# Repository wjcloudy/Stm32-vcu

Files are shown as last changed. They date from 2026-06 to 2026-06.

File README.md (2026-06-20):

# stm32-vcu (ZombieVerter VCU)

Build status

Project based on the OpenInverter System by Johannes Huebner to provide a universal VCU (Vehicle Control Unit) for electric vehicle conversion projects. 

Please visit the development thread on the Openinverter Forum for more information : https://openinverter.org/forum/viewtopic.php?f=3&t=1277
Zom_V1_3

V1.3 Hardware now released. PDFs and Gerber here on Github, full Kicad 9 design is on Patreon at the 10Eur level.

## Videos on progress

Project introduction : https://vimeo.com/506480876

V1.11a On dyno with GS450h / BMW E39 : https://vimeo.com/802405172

V2.00a now available : https://vimeo.com/824494783?share=copy

V2.15a now available : https://www.youtube.com/watch?v=iwB3wxCEFo0

V2.20A now available : https://www.youtube.com/watch?v=wjlucUWX_lc

V2.40A now available : https://vimeo.com/1201141543?fl=ip&fe=ec

# Supported components

- Nissan Leaf Gen1/2/3 inverter via CAN
- Nissan Leaf Gen1/2/3 PDM (Charger and DCDC)
- Nissan LEAF Battery (all variants)
- Mitsubishi Outlander Support
- Mitsubishi Outlander drivetrain (front and rear motors/inverters) Support
- Modular BMS / SimpBMS Support
- OpenInverter CAN Support
- CCS DC fast charge via BMW i3 LIM
- CCS DC fast charging via FOCCCI https://github.com/uhi22/ccs32clara
- Chademo DC fast charge
- ISA Shunt / BMW SBOX / VW EBOX supported via CAN
- Lexus GS450H inverter / gearbox via sync serial
- Lexus GS300H inverter / gearbox via sync serial
- Toyota Prius/Yaris/Auris Gen 3 inverters via sync serial
- BMW E46 CAN support
- BMW E39 CAN support
- BMW E65 CAN Support
- BMW E31 CAN Support
- Mid 2000s VAG Can support
- Subaru vehicle support
- Opel Ampera / Chevy Volt 6.5kw cabin heater
- VW LIN based 6.5kw cabin heater
- Elcon charger Support
- OBD2 Can support
- TESLA Gen 2 DCDC Converter Can support

# Contributing

Information on how to contribute to this open source project can be found [Contributing Guide](./CONTRIBUTING.md)

# Compiling
You will need the arm-none-eabi toolchain: https://developer.arm.com/open-source/gnu-toolchain/gnu-rm/downloads
On Linux this can be installed by typing:

`sudo apt install gcc-arm-none-eabi`

The only external depedencies are libopencm3 and libopeninv. You can download and build this dependency by typing

`make get-deps`

Now you can compile stm32-vcu by typing

`make`

# Tests

Build the tests

`make Tests`

Run the tests

`./test/test_vcu`

And upload it to your board using a JTAG/SWD adapter, the updater.py script or the esp8266 web interface

I use CodeBlocks IDE :  https://www.codeblocks.org/

Sept 21 : V1 hardware and firmware from "Master" branch now running in my E46 Touring and E39 vehicles.

March 24 : V1.1 Hardware and V2.05A firmware now running in 3 vehicles :

-BMW E39 with Lexus GS450H Drivetrain, Tesla PCS, ISA Shunt , Chademo Fast Charge

-BMW E46 Touring with Nissan Leaf Gen 1 Drivetrain, Outlander Charger / DCDC, ISA Shunt , CCS Fast Charge

-BMW E31 with Tesla LDU Drivetrain, Tesla DCDC, ISA Shunt , Chademo Fast Charge

All hardware / software is tested in these vehicles before release. More vehicles with different configuration in progress to ensure as much testing as possible.

Apr 26 : Added Zombie Relay box V1 full kicad project to hardware directory.

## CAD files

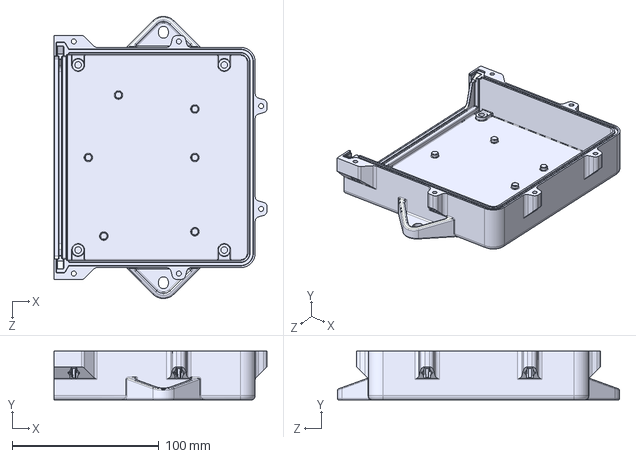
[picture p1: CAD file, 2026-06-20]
3d_Printable_Case/zombiecase_V3.1_2mounts_169mm.STEP
145.0 x 33.4 x 192.0 mm

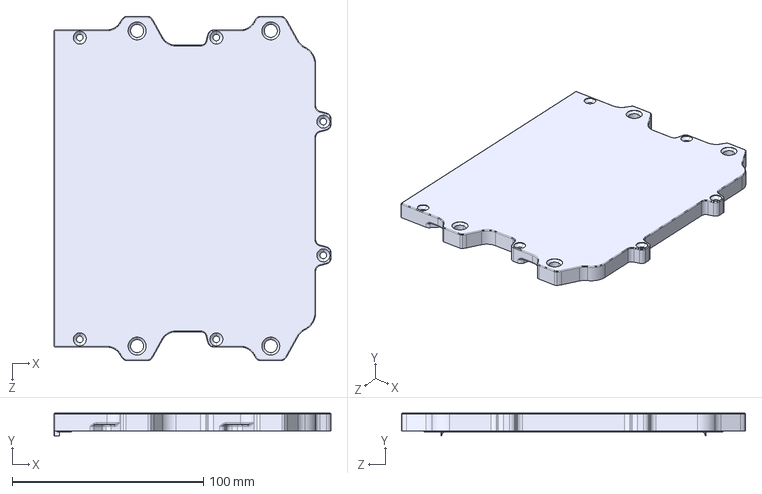
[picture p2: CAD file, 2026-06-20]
3d_Printable_Case/Zombiecase_StackingTopV3.2.STEP
145.0 x 12.0 x 180.1 mm

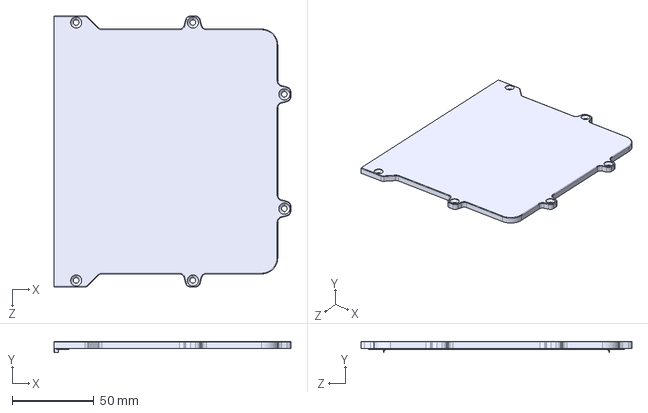
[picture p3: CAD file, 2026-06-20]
3d_Printable_Case/Zombiecase_topV3.1.STEP
145.0 x 6.95 x 166.0 mm

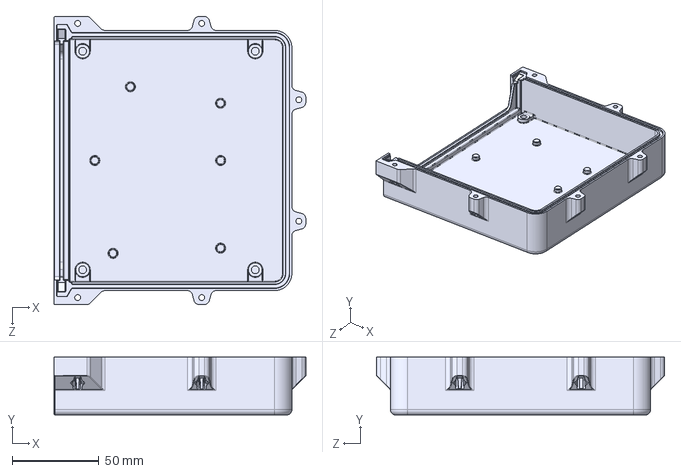
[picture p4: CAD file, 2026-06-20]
3d_Printable_Case/zombiecase_V3.1.STEP
145.0 x 33.4 x 166.0 mm

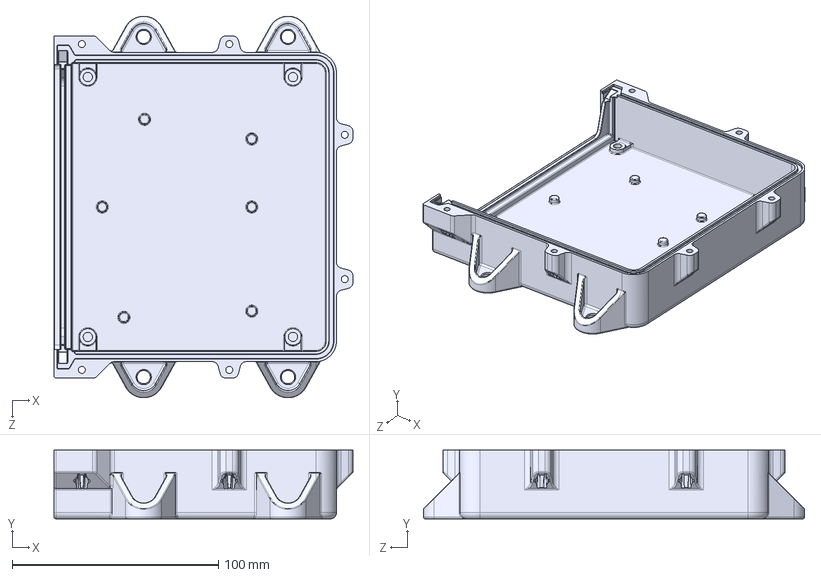
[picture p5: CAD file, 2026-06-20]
3d_Printable_Case/zombiecase_V3.1wMountingTabs.STEP
145.0 x 33.4 x 185.0 mm

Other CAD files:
3d_Printable_Case/Zombiecase_StackingTopV3.2.3MF
3d_Printable_Case/zombiecase_V3.1_2mounts_169mm.3MF

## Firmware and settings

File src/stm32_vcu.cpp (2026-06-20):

/*
 * This file is part of the ZombieVerter project.
 *
 * Copyright (C) 2024 Tom de Bree <tom@voltinflux.com>
 * Copyright (C) 2010 Johannes Huebner <contact@johanneshuebner.com>
 * Copyright (C) 2010 Edward Cheeseman <cheesemanedward@gmail.com>
 * Copyright (C) 2009 Uwe Hermann <uwe@hermann-uwe.de>
 * Copyright (C) 2019-2022 Damien Maguire <info@evbmw.com>
 *
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
 * You should have received a copy of the GNU General Public License
 * along with this program.  If not, see <http://www.gnu.org/licenses/>.
 */

#include "BMW_E31.h"
#include "BMW_E39.h"
#include "BMW_E65.h"
/*
 * BMW PHEV SME integration (BmwPhevBMS):
 *   BMS_Mode=6  →  cell Vmin/Vmax, Tmin/Tmax, SOC, isolation, power limits
 *   ShuntType=5  →  pack voltage/current, precharge setpoint, contactor control
 * Both params must point to the same CAN bus (BMSCan = ShuntCan).
 * See include/bmw_phev_bms.h for the full protocol documentation.
 */
#include "CANSPI.h"
#include "CPC.h"
#include "Can_OBD2.h"
#include "Can_OI.h"
#include "Can_VAG.h"
#include "E65_Lever.h"
#include "ElconCharger.h"
#include "ElconDCDC.h"
#include "F30_Lever.h"
#include "Foccci.h"
#include "GS450H.h"
#include "JLR_G1.h"
#include "JLR_G2.h"
#include "MGCoolantHeater.h"
#include "NissanPDM.h"
#include "NoInverter.h"
#include "NoVehicle.h"
#include "OutlanderCanHeater.h"
#include "OutlanderHeartBeat.h"
#include "TeslaDCDC.h"
#include "VWAirHeater.h"
#include "VWCoolantHeater.h"
#include "V_Classic.h"
#include "amperacharger.h"
#include "amperaheater.h"
#include "anain.h"
#include "bms.h"
#include "bmw_phev_bms.h" // BMW PHEV Gen3/4 SME — BMS + contactor control
#include "bmw_sbox.h"
#include "canmap.h"
#include "cansdo.h"
#include "chademo.h"
#include "chargerhw.h"
#include "chargerint.h"
#include "daisychainbms.h"
#include "dcdc.h"
#include "digio.h"
#include "digipot.h"
#include "errormessage.h"
#include "extCharger.h"
#include "heater.h"
#include "hwdefs.h"
#include "hwinit.h"
#include "i3LIM.h"
#include "inverter.h"
#include "iomatrix.h"
#include "isa_shunt.h"
#include "kangoobms.h"
#include "leafbms.h"
#include "leafinv.h"
#include "linbus.h"
#include "my_math.h"
#include "my_string.h"
#include "noHeater.h"
#include "no_Lever.h"
#include "nocharger.h"
#include "notused.h"
#include "outlanderCharger.h"
#include "outlanderinverter.h"
#include "param_save.h"
#include "params.h"
#include "preheater.h"
#include "printf.h"
#include "rearoutlanderinverter.h"
#include "sdocommands.h"
#include "shifter.h"
#include "simpbms.h"
#include "stm32_can.h"
#include "stm32scheduler.h"
#include "subaruvehicle.h"
#include "temp_meas.h"
#include "terminal.h"
#include "terminalcommands.h"
#include "teslaCharger.h"
#include "throttle.h"
#include "utils.h"
#include "vag_sbox.h"
#include "vehicle.h"
#include <libopencm3/stm32/can.h>
#include <libopencm3/stm32/exti.h>
#include <libopencm3/stm32/iwdg.h>
#include <libopencm3/stm32/rtc.h>
#include <libopencm3/stm32/spi.h>
#include <libopencm3/stm32/timer.h>
#include <libopencm3/stm32/usart.h>
#include <stdint.h>

#define PRECHARGE_TIMEOUT 5 // 5s

#define PRINT_JSON 0

extern "C" void __cxa_pure_virtual() {
  while (1)
    ;
}

static Stm32Scheduler *scheduler;
static bool chargeMode = false;
static bool chargeModeDC = false;
static bool ChgLck = false;
static CanHardware *canInterface[3];
static CanMap *canMap;
static CanSdo *canSdo;
static ChargeModes targetCharger;
static ChargeInterfaces targetChgint;
static uint8_t ChgSet; // Temp variable storing Param::Chgctrl. 0=enable,
                       // 1=disable, 2=timer.
static bool RunChg;
static uint8_t ChgHrs_tmp;
static uint8_t ChgMins_tmp;
static uint16_t ChgDur_tmp;
static uint32_t ChgTicks = 0, ChgTicks_1Min = 0;
static bool StartSig = false;
static bool ACrequest = false;
static bool initbyStart = false;
static bool initbyCharge = false;
static bool OutlanderCAN = false;
static bool ExtHVreq = false;
static bool CheckHVIL = 0;
static bool HVILok = 0;

static volatile unsigned days = 0, hours = 0, minutes = 0, seconds = 0,
                         alarm = 0; // != 0 when alarm is pending

static uint16_t rlyDly = 25;
static uint16_t prechargeMinTime = 100;

// Instantiate Classes
static BMW_E31 e31Vehicle;
static BMW_E65 e65Vehicle;
static BMW_E39 e39Vehicle;
static Can_VAG vagVehicle;
static SubaruVehicle subaruVehicle;
static GS450HClass gs450Inverter;
static LeafINV leafInv;
static NissanPDM chargerPDM;
static teslaCharger ChargerTesla;
static ElconCharger ChargerElcon;
static notused UnUsed;
static noCharger nochg;
static extCharger chgdigi;
static amperaCharger ampChg;
static outlanderCharger outChg;
static FCChademo chademoFC;
static i3LIMClass LIMFC;
static CPCClass CPCcan;
static FoccciClass Focccican;
static Can_OI openInv;
static NoInverterClass NoInverter;
static OutlanderInverter outlanderInv;
static noHeater Heaternone;
static AmperaHeater amperaHeater;
static OutlanderCanHeater outlanderCanHeater;
static no_Lever NoGearLever;
static F30_Lever F30GearLever;
static E65_Lever E65GearLever;
static JLR_G1 JLRG1shift;
static JLR_G2 JLRG2shift;
static vwCoolantHeater heaterCoolantVW;
static mgCoolantHeater heaterCoolantMG;
static vwAirHeater heaterAirVW;
static NoVehicle VehicleNone;
static V_Classic classVehicle;
static Inverter *selectedInverter = &openInv;
static Vehicle *selectedVehicle = &VehicleNone;
static Heater *selectedHeater = &Heaternone;
static Chargerhw *selectedCharger = &chargerPDM;
static Chargerint *selectedChargeInt = &UnUsed;
static Shifter *selectedShifter = &NoGearLever;
static BMS BMSnone;
static SimpBMS BMSsimp;
static LeafBMS BMSleaf;
static DaisychainBMS BMSdaisychain;
static KangooBMS BMSRenaultKangoo33;
static BmwPhevBMS
    BMSbmwphev; // BMW PHEV SME — used when BMS_Mode=6 and ShuntType=5
static DCDC DCDCnone;
static TeslaDCDC DCDCTesla;
static ElconDCDC ElconDC;
static BMS *selectedBMS = &BMSnone;
static DCDC *selectedDCDC = &DCDCnone;
static Can_OBD2 canOBD2;
static Shifter shifterNone;
static RearOutlanderInverter rearoutlanderInv;
static LinBus *lin;
static Preheater preheater;

///////////////////////////////////////////////////////////////////////////////////////////////////////////////////////////////
static void Ms200Task(void) {
  int opmode = Param::GetInt(Param::opmode);

  selectedVehicle->Task200Ms();
  if (opmode == MOD_CHARGE)
    selectedCharger->Task200Ms();

  // in chademo , we do not want to run the 200ms task unless in dc charge mode
  if (targetChgint == ChargeInterfaces::Chademo && chargeModeDC)
    selectedChargeInt->Task200Ms();
  // In case of the LIM we want to send it all the time if lim in use
  if ((targetChgint == ChargeInterfaces::i3LIM) ||
      (targetChgint == ChargeInterfaces::Unused) ||
      (targetChgint == ChargeInterfaces::CPC) ||
      (targetChgint == ChargeInterfaces::Foccci))
    selectedChargeInt->Task200Ms();
  // and just to be thorough ...
  if (targetChgint == ChargeInterfaces::Unused)
    selectedChargeInt->Task200Ms();

  // if(opmode==MOD_CHARGE) utils::CpSpoofOutput;
  utils::CpSpoofOutput();

  Param::SetInt(Param::Day, days);
  Param::SetInt(Param::Hour, hours);
  Param::SetInt(Param::Min, minutes);
  Param::SetInt(Param::Sec, seconds);
  Param::SetInt(Param::uptime, rtc_get_counter_val());
  Param::SetInt(Param::ChgT, ChgDur_tmp);

  // Setting of RunChg - main okay to charge param

  if (ChgSet == 2 && !ChgLck) // if in timer mode and not locked out from a
                              // previous full charge.
  {
    if (opmode != MOD_CHARGE) {
      if ((ChgHrs_tmp == hours) && (ChgMins_tmp == minutes) &&
          (ChgDur_tmp != 0))
        RunChg = true; // if we arrive at set charge time and duration is non
                       // zero then initiate charge
      else
        RunChg = false;
    }

    if (opmode == MOD_CHARGE) {
      if (ChgTicks != 0) {
        ChgTicks--; // decrement charge timer ticks
        ChgTicks_1Min++;
      }

      if (ChgTicks == 0) {
        RunChg = false; // end charge if still charging once timer expires.
        ChgTicks = (GetInt(Param::Chg_Dur) * 300); // recharge the tick timer
      }

      if (ChgTicks_1Min == 300) {
        ChgTicks_1Min = 0;
        ChgDur_tmp--; // countdown minutes of charge time remaining.
      }
    }
  }
  if (ChgSet == 0 && !ChgLck)
    RunChg = true; // enable from webui if we are not locked out from an auto
                   // termination
  if (ChgSet == 1)
    RunChg = false; // disable from webui

  // Handle PP on the Charging port - Changes RunChg
  if (Param::GetInt(Param::GPA1Func) == IOMatrix::PILOT_PROX ||
      Param::GetInt(Param::GPA2Func) == IOMatrix::PILOT_PROX) {
    int ppThresh = Param::GetInt(Param::ppthresh);
    int ppValue = IOMatrix::GetAnaloguePin(IOMatrix::PILOT_PROX)->Get();
    Param::SetInt(Param::PPVal, ppValue);

    // If PP is at or below threshold and currently disabled and not already
    // finished
    if (ppValue <= ppThresh) {
      if (ChgSet == 1 && !ChgLck) {
        RunChg = true;
      }
      Param::SetInt(Param::PlugDet, 1);
    } else if (ppValue > ppThresh) {
      // even if timer was enabled, change to disabled, we've unplugged
      RunChg = false;
      Param::SetInt(Param::PlugDet, 0);
    }
  }
  // END Setting of RunChg - main okay to charge param

  // Check if we want to AC charge via charger
  if (selectedCharger->ControlCharge(RunChg, ACrequest) &&
      (opmode != MOD_RUN)) {
    chargeMode = true; // AC charge mode
    Param::SetInt(Param::chgtyp, AC);
  } else if (!chargeModeDC) {
    Param::SetInt(Param::chgtyp, OFF);
    chargeMode = false; // no charge mode
  }
  // end check

  ///////////////////////////////////////
  // Charge term logic for AC charge
  ///////////////////////////////////////
  /*
  if we are in charge mode and battV >= setpoint and power is <= termination
  setpoint Then we end charge.
  */
  if (opmode == MOD_CHARGE && !chargeModeDC) {
    if (Param::GetInt(Param::udc) >= Param::GetInt(Param::Voltspnt) &&
        Param::GetInt(Param::idc) <= Param::GetInt(Param::IdcTerm)) {
      RunChg = false; // end charge
      ChgLck = true;  // set charge lockout flag
    }

    if (selectedBMS->MaxChargeCurrent() ==
        0) // BMS can command an AC charge shutdown if its current limit is 0
    {
      RunChg = false; // end charge
      ChgLck = true;  // set charge lockout flag
    }
  }
  // End Charge Term Logic

  if (opmode == MOD_RUN) {
    ChgLck = false; // reset charge lockout flag when we drive off

    // Brake Vac Sensor
    if (Param::GetInt(Param::GPA1Func) == IOMatrix::VAC_SENSOR ||
        Param::GetInt(Param::GPA2Func) == IOMatrix::VAC_SENSOR) {
      int brkVacThresh = Param::GetInt(Param::BrkVacThresh);
      int BrkVacHyst = Param::GetInt(Param::BrkVacHyst);

      int brkVacVal = IOMatrix::GetAnaloguePin(IOMatrix::VAC_SENSOR)->Get();
      Param::SetInt(Param::BrkVacVal, brkVacVal);

      // if brkVacThresh > BrkVacHyst then sensor reads higher with more vacuum
      // else other way round
      if (brkVacThresh > BrkVacHyst) {
        // enable pump
        if (brkVacVal > brkVacThresh) {
          IOMatrix::GetPinOut(IOMatrix::BRAKEVACPUMP)->Clear();
        } else if (brkVacVal < BrkVacHyst) {
          IOMatrix::GetPinOut(IOMatrix::BRAKEVACPUMP)->Set();
        }
      } else {
        // enable pump
        if (brkVacVal < brkVacThresh) {
          IOMatrix::GetPinOut(IOMatrix::BRAKEVACPUMP)->Clear();
        } else if (brkVacVal > BrkVacHyst) {
          IOMatrix::GetPinOut(IOMatrix::BRAKEVACPUMP)->Set();
        }
      }
    }
  } else {
    // IOMatrix::GetPinOut(IOMatrix::BRAKEVACPUMP)->Clear();
  }

  preheater.Task200Ms(opmode, hours, minutes);
}

static void Ms100Task(void) {
  DigIo::led_out.Toggle();
  iwdg_reset();
  float cpuLoad = scheduler->GetCpuLoad() / 10.0f;
  Param::SetFloat(Param::cpuload, cpuLoad);
  Param::SetInt(Param::lasterr, ErrorMessage::GetLastError());
  int opmode = Param::GetInt(Param::opmode);
  utils::SelectDirection(selectedVehicle, selectedShifter);

  if (Param::GetInt(Param::ShuntType) != 0) // Do not do any SOC calcs
  {
    utils::CalcSOC();
  }

  Param::SetInt(Param::cruisestt, selectedVehicle->GetCruiseState());
  Param::SetFloat(Param::FrontRearBal, selectedVehicle->GetFrontRearBalance());

  utils::ProcessCruiseControlButtons();

  selectedInverter->Task100Ms();
  selectedVehicle->Task100Ms();
  selectedCharger->Task100Ms();
  selectedBMS->Task100Ms();
  selectedDCDC->Task100Ms();
  selectedShifter->Task100Ms();
  selectedHeater->Task100Ms();
  canMap->SendAll();
  canSdo->TriggerTimeout(100);

  if (OutlanderCAN == true) {
    OutlanderHeartBeat::Task100Ms();
  }

  // Setting reverse light
  if (Param::GetInt(Param::dir) < 0) {
    IOMatrix::GetPinOut(IOMatrix::REVERSELIGHT)->Set();
  } else {
    IOMatrix::GetPinOut(IOMatrix::REVERSELIGHT)->Clear();
  }

  // Setting Run light
  if (opmode == MOD_RUN) {
    IOMatrix::GetPinOut(IOMatrix::RUNINDICATION)->Set();
  } else {
    IOMatrix::GetPinOut(IOMatrix::RUNINDICATION)->Clear();
  }
  // end lights

  Param::SetFloat(
      Param::tmphs,
      selectedInverter
          ->GetInverterTemperature()); // send inverter temp to web interface
  Param::SetFloat(
      Param::tmpm,
      selectedInverter
          ->GetMotorTemperature()); // send motor temp to web interface
  Param::SetFloat(
      Param::InvStat,
      selectedInverter
          ->GetInverterState()); // update inverter status on web interface
  Param::SetFloat(
      Param::INVudc,
      selectedInverter->GetInverterVoltage()); // display inverter derived dc
                                               // link voltage on web interface

  Param::SetInt(Param::T15Stat, selectedVehicle->Ready());

  // Needs to move to shunt handling
  int32_t IsaTemp = ISA::Temperature;
  Param::SetInt(Param::tmpaux, IsaTemp);
  // end need to move

  // Charge interface logic
  if (targetChgint == ChargeInterfaces::i3LIM ||
      targetChgint == ChargeInterfaces::Foccci || chargeModeDC)
    selectedChargeInt
        ->Task100Ms(); // send the 100ms task request for the lim all the time
                       // and for others if in DC charge mode

  if (selectedChargeInt->DCFCRequest(RunChg) ||
      ExtHVreq) // Request to run dc fast charge via charge interface or
                // external pin io
  {
    // Here we receive a valid DCFC startup request.
    if (opmode != MOD_RUN)
      chargeMode = true; // set charge mode to true to bring up hv
    chargeModeDC = true; // DC charge mode on
  } else if (chargeModeDC) {
    Param::SetInt(Param::chgtyp, OFF);
    chargeMode = false;   // no charge mode
    chargeModeDC = false; // DC charge mode off
  }

  if (!chargeModeDC) // Request to run ac charge from the interface (e.g. LIM)
                     // if we are NOT in DC charge mode.
  {
    ACrequest = selectedChargeInt->ACRequest(
        RunChg); // If using unused always returns true
  }
  // End charge interface logic

  // Reading HeatReq inpput
  if (IOMatrix::GetPinIn(IOMatrix::HEATREQ) !=
      &DigIo::dummypin) // digital input has priority, check if used
  {
    Param::SetInt(Param::HeatReq, IOMatrix::GetPinIn(IOMatrix::HEATREQ)->Get());
  } else if (Param::GetInt(Param::GPA1Func) == IOMatrix::HEATER_POT ||
             Param::GetInt(Param::GPA2Func) ==
                 IOMatrix::HEATER_POT) // check if Anolgue Heater input used
  {
    int htrPotVal = IOMatrix::GetAnaloguePin(IOMatrix::HEATER_POT)
                        ->Get(); // Get input value
    Param::SetInt(Param::HtPotVal, htrPotVal);

    if (Param::GetInt(Param::HeatPotDir) == 2 ||
        Param::GetInt(Param::HeatPotDir) ==
            3) // If higher then threshold is HEAT ON
    {

      if (htrPotVal >
          Param::GetInt(Param::HeatPotOn)) // if value is above threshold
      {
        if (Param::GetInt(Param::HeatPotDir) == 3)
          Param::SetInt(
              Param::HeatPercnt,
              utils::change(htrPotVal, Param::GetInt(Param::HeatPotOn),
                            Param::GetInt(Param::HeatPotFull), 0,
                            100));        // map threshold to 0 and full to 100
        Param::SetInt(Param::HeatReq, 1); // On
      } else {
        Param::SetInt(Param::HeatReq, 0); // Off
      }
    } else if (Param::GetInt(Param::HeatPotDir) == 0 ||
               Param::GetInt(Param::HeatPotDir) ==
                   1) // If higher then threshold is HEAT ON
    {
      if (htrPotVal <
          Param::GetInt(Param::HeatPotOn)) // if value is below threshold
      {
        if (Param::GetInt(Param::HeatPotDir) == 1)
          Param::SetInt(
              Param::HeatPercnt,
              utils::change(htrPotVal, Param::GetInt(Param::HeatPotOn),
                            Param::GetInt(Param::HeatPotFull), 0,
                            100));        // map threshold to 100 and full to 0
        Param::SetInt(Param::HeatReq, 1); // On
      } else {
        Param::SetInt(Param::HeatReq, 0); // Of
      }
    }
  }

  // Reading HVrequest inpput
  if (IOMatrix::GetPinIn(IOMatrix::HVREQ) != &DigIo::dummypin) {
    ExtHVreq = IOMatrix::GetPinIn(IOMatrix::HVREQ)
                   ->Get(); // Read IO pin to determine if there is an external
                            // HV request
    if (ExtHVreq)
      Param::SetInt(Param::chgtyp, DCEXT);
  }

  DigiPot::SetPot1Step(); // just for dev
  DigiPot::SetPot2Step(); // just for dev

  // Reading HVIL input
  if (IOMatrix::GetPinIn(IOMatrix::HVIL) != &DigIo::dummypin) {
    CheckHVIL = IOMatrix::GetPinIn(IOMatrix::HVIL)->Get();
    if (CheckHVIL > 0) {
      HVILok = 1;
    } else {
      HVILok = 0;
      ErrorMessage::Post(ERR_HVILERR);
    }
  } else {
    HVILok = 1;
  }

  // Cooling Fan Control//
  if (opmode == MOD_CHARGE || opmode == MOD_RUN) {
    float tempTemp =
        MAX(Param::GetFloat(Param::tmphs), Param::GetFloat(Param::ChgTemp));

    if (Param::GetFloat(Param::FanTemp) < tempTemp) {
      IOMatrix::GetPinOut(IOMatrix::COOLINGFAN)->Set(); // Coolant Fan On
    } else if ((Param::GetFloat(Param::FanTemp) - 5) > tempTemp) {
      IOMatrix::GetPinOut(IOMatrix::COOLINGFAN)->Clear(); // Coolant Fan Off
    }
  } else {
    IOMatrix::GetPinOut(IOMatrix::COOLINGFAN)->Clear(); // Coolant Fan Off
  }

  // HV Active output
  if (opmode == MOD_CHARGE || opmode == MOD_RUN || opmode == MOD_PREHEAT) {
    IOMatrix::GetPinOut(IOMatrix::HVACTIVE)->Set(); // HV Active On
  } else {
    IOMatrix::GetPinOut(IOMatrix::HVACTIVE)->Clear(); // HV Active Off
  }

  // ShiftLock Out output
  if (opmode == MOD_RUN && Param::GetInt(Param::ShiftLock) == 1) {
    IOMatrix::GetPinOut(IOMatrix::SHIFTLOCKNO)->Set(); // Shift Lock Out On
  } else {
    IOMatrix::GetPinOut(IOMatrix::SHIFTLOCKNO)->Clear(); // Shift Lock Out Off
  }
}
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
int main(void) {
  extern const TERM_CMD TermCmds[];

  clock_setup();
  rtc_setup();
  ConfigureVariantIO();
  gpio_primary_remap(AFIO_MAPR_SWJ_CFG_JTAG_OFF_SW_ON,
                     AFIO_MAPR_CAN2_REMAP |
                         AFIO_MAPR_TIM1_REMAP_FULL_REMAP); // 32f107
  usart2_setup(); // TOYOTA HYBRID INVERTER INTERFACE
  nvic_setup();
  parm_load();
  spi2_setup();
  spi3_setup();
  tim3_setup(); // For general purpose PWM output
  Param::Change(Param::PARAM_LAST);
  DigIo::inv_out.Clear(); // inverter power off during bootup
  DigIo::mcp_sby.Clear(); // enable can3

  Terminal t(USART3, TermCmds, false, true, !Param::GetBool(Param::UseRS232));
  //   FunctionPointerCallback canCb(CanCallback, SetCanFilters);
  Stm32Can c(CAN1, CanHardware::Baud500);
  Stm32Can c2(CAN2, CanHardware::Baud500, true);
  FunctionPointerCallback cb(CanCallback, SetCanFilters);
  Stm32Can *CanMapDev = &c;
  if (Param::GetInt(Param::CanMapCan) == 0) {
    CanMapDev = &c;
  } else {
    CanMapDev = &c2;
  }
  CanMap cm(CanMapDev);
  CanSdo sdo(&c, &cm);
  sdo.SetNodeId(3); // id 3 for vcu?
  // Set up CAN 1 callback and messages to listen for
  //  c.AddReceiveCallback(&canCb);
  //  c2.AddReceiveCallback(&canCb);
  canInterface[0] = &c;
  canInterface[1] = &c2;
  c.AddCallback(&cb);
  c2.AddCallback(&cb);
  TerminalCommands::SetCanMap(&cm);
  SdoCommands::SetCanMap(&cm);
  canMap = &cm;
  canSdo = &sdo;

  CanHardware *shunt_can = canInterface[Param::GetInt(Param::ShuntCan)];

  canOBD2.SetCanInterface(canInterface[Param::GetInt(Param::OBD2Can)]);

  CANSPI_Initialize(); // init the MCP25625 on CAN3
  CANSPI_ENRx_IRQ();   // init CAN3 Rx IRQ

  LinBus l(USART1, 19200);
  lin = &l;

  UpdateInv();
  UpdateVehicle();
  UpdateCharger();
  UpdateChargeInt();
  UpdateBMS();
  UpdateHeater();
  UpdateDCDC();
  UpdateShifter();

  Stm32Scheduler s(TIM4); // We never exit main so it's ok to put it on stack
  scheduler = &s;

  s.AddTask(Ms1Task, 1);
  s.AddTask(Ms10Task, 10);
  s.AddTask(Ms100Task, 100);
  s.AddTask(Ms200Task, 200);

  if (Param::GetInt(Param::IsaInit) == 1)
    ISA::initialize(shunt_can); // only call this once if a new sensor is
                                // fitted.

  Param::SetInt(Param::version, 4);      // backward compatibility
  Param::SetInt(Param::opmode, MOD_OFF); // always off at startup

  while (1) {
    char c = 0;
    CanSdo::SdoFrame *sdoFrame = sdo.GetPendingUserspaceSdo();
    t.Run();
    if (sdo.GetPrintRequest() == PRINT_JSON) {
      TerminalCommands::PrintParamsJson(&sdo, &c);
    }
    if (0 != sdoFrame) {
      SdoCommands::ProcessStandardCommands(sdoFrame);

      sdo.SendSdoReply(sdoFrame);
    }
  }

  return 0;
}

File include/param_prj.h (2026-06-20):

/*
 * This file is part of the ZombieVerter project.
 *
 * Copyright (C) 2011-2019 Johannes Huebner <dev@johanneshuebner.com>
 * Copyright (C) 2019-2022 Damien Maguire <info@evbmw.com>
 * Changes by Tom de Bree <tom@voltinflux.com> 2024
 *
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
 * You should have received a copy of the GNU General Public License
 * along with this program.  If not, see <http://www.gnu.org/licenses/>.
 */

#define VER 2.41A

/* Entries must be ordered as follows:
   1. Saveable parameters (id != 0)
   2. Temporary parameters (id = 0)
   3. Display values
 */
// Next param id (increase when adding new parameter!): 157
/*              category     name         unit       min     max     default id
 */
#define PARAM_LIST                                                             \
  PARAM_ENTRY(CAT_SETUP, Inverter, INVMODES, 0, 8, 0, 5)                       \
  PARAM_ENTRY(CAT_SETUP, Vehicle, VEHMODES, 0, 8, 0, 6)                        \
  PARAM_ENTRY(CAT_SETUP, GearLvr, SHIFTERS, 0, 4, 0, 108)                      \
  PARAM_ENTRY(CAT_SETUP, Transmission, TRNMODES, 0, 1, 0, 78)                  \
  PARAM_ENTRY(CAT_SETUP, interface, CHGINT, 0, 4, 0, 39)                       \
  PARAM_ENTRY(CAT_SETUP, chargemodes, CHGMODS, 0, 6, 0, 37)                    \
  PARAM_ENTRY(CAT_SETUP, BMS_Mode, BMSMODES, 0, 6, 0, 90)                      \
  PARAM_ENTRY(CAT_SETUP, ShuntType, SHNTYPE, 0, 5, 0, 88)                      \
  PARAM_ENTRY(CAT_SETUP, InverterCan, CAN_DEV, 0, 1, 0, 70)                    \
  PARAM_ENTRY(CAT_SETUP, VehicleCan, CAN_DEV, 0, 1, 1, 71)                     \
  PARAM_ENTRY(CAT_SETUP, ShuntCan, CAN_DEV, 0, 1, 0, 72)                       \
  PARAM_ENTRY(CAT_SETUP, LimCan, CAN_DEV, 0, 1, 0, 73)                         \
  PARAM_ENTRY(CAT_SETUP, ChargerCan, CAN_DEV, 0, 1, 1, 74)                     \
  PARAM_ENTRY(CAT_SETUP, BMSCan, CAN_DEV, 0, 1, 1, 89)                         \
  PARAM_ENTRY(CAT_SETUP, OBD2Can, CAN_DEV, 0, 1, 0, 96)                        \
  PARAM_ENTRY(CAT_SETUP, CanMapCan, CAN_DEV, 0, 1, 0, 97)                      \
  PARAM_ENTRY(CAT_SETUP, DCDCCan, CAN_DEV, 0, 1, 1, 107)                       \
  PARAM_ENTRY(CAT_SETUP, HeaterCan, CAN_DEV, 0, 1, 1, 138)                     \
  PARAM_ENTRY(CAT_SETUP, MotActive, MotorsAct, 0, 3, 0, 129)                   \
  PARAM_ENTRY(CAT_SETUP, ConfigCANOI, ONOFF, 0, 1, 0, 149)                     \
  PARAM_ENTRY(CAT_SETUP, UseRS232, ONOFF, 0, 1, 0, 155)                        \
  PARAM_ENTRY(CAT_SETUP, DriveInhibit, DRIVEINHIBITMODES, 0, 1, 0, 156)        \
  PARAM_ENTRY(CAT_THROTTLE, potmin, "dig", 0, 4095, 0, 7)                      \
  PARAM_ENTRY(CAT_THROTTLE, potmax, "dig", 0, 4095, 4095, 8)                   \
  PARAM_ENTRY(CAT_THROTTLE, pot2min, "dig", 0, 4095, 4095, 9)                  \
  PARAM_ENTRY(CAT_THROTTLE, pot2max, "dig", 0, 4095, 4095, 10)                 \
  PARAM_ENTRY(CAT_THROTTLE, regenrpm, "rpm", 100, 10000, 1500, 60)             \
  PARAM_ENTRY(CAT_THROTTLE, regenendrpm, "rpm", 100, 10000, 100, 126)          \
  PARAM_ENTRY(CAT_THROTTLE, regenmax, "%", -35, 0, -10, 61)                    \
  PARAM_ENTRY(CAT_THROTTLE, regenBrake, "%", -35, 0, -10, 122)                 \
  PARAM_ENTRY(CAT_THROTTLE, regenramp, "%/10ms", 0.1, 100, 1, 68)              \
  PARAM_ENTRY(CAT_THROTTLE, potmode, POTMODES, 0, 1, 0, 11)                    \
  PARAM_ENTRY(CAT_THROTTLE, dirmode, DIRMODES, 0, 4, 1, 12)                    \
  PARAM_ENTRY(CAT_THROTTLE, DirChange, DIRLIM, 0, 2, 0, 147)                   \
  PARAM_ENTRY(CAT_THROTTLE, DirChangeRpm, "rpm", 0, 20000, 500, 139)           \
  PARAM_ENTRY(CAT_THROTTLE, reversemotor, ONOFF, 0, 1, 0, 127)                 \
  PARAM_ENTRY(CAT_THROTTLE, throtramp, "%/10ms", 0.1, 100, 10, 13)             \
  PARAM_ENTRY(CAT_THROTTLE, throtramprpm, "rpm", 0, 20000, 20000, 14)          \
  PARAM_ENTRY(CAT_THROTTLE, revlim, "rpm", 0, 20000, 6000, 15)                 \
  PARAM_ENTRY(CAT_THROTTLE, revRegen, ONOFF, 0, 1, 0, 137)                     \
  PARAM_ENTRY(CAT_THROTTLE, udcmin, "V", 0, 1000, 450, 19)                     \
  PARAM_ENTRY(CAT_THROTTLE, udclim, "V", 0, 1000, 520, 20)                     \
  PARAM_ENTRY(CAT_THROTTLE, idcmax, "A", 0, 5000, 5000, 21)                    \
  PARAM_ENTRY(CAT_THROTTLE, idcmin, "A", -5000, 0, -5000, 22)                  \
  PARAM_ENTRY(CAT_THROTTLE, tmphsmax, "°C", 50, 150, 85, 23)                   \
  PARAM_ENTRY(CAT_THROTTLE, tmpmmax, "°C", 70, 300, 300, 24)                   \
  PARAM_ENTRY(CAT_THROTTLE, throtmax, "%", 0, 100, 100, 25)                    \
  PARAM_ENTRY(CAT_THROTTLE, throtmin, "%", -100, 0, -100, 26)                  \
  PARAM_ENTRY(CAT_THROTTLE, throtmaxRev, "%", 0, 100, 30, 123)                 \
  PARAM_ENTRY(CAT_THROTTLE, throtdead, "%", 0, 50, 10, 76)                     \
  PARAM_ENTRY(CAT_THROTTLE, RegenBrakeLight, "%", -100, 0, -15, 128)           \
  PARAM_ENTRY(CAT_THROTTLE, throtrpmfilt, "rpm/10ms", 0.1, 200, 15, 131)       \
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

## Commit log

2026-06-12 Block flash saves unless fully in OFF mode
    Saving parameters/CAN mappings runs with all interrupts disabled for
    ~100-300ms (two flash page erases plus programming). This stops the
    contactor keep-alive frames, causing external BMS/SME units to drop
    their contactors under load and re-close them after the save.
    Drive the existing TerminalCommands/SdoCommands saveEnabled guard from
    the opmode state machine: saving is only allowed in MOD_OFF after the
    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
2026-06-12 Add BMW PHEV Gen3/4 SME battery integration (BMS_Mode=6, ShuntType=5)
    - UDS polling for cell voltages, SOC, SOH, isolation and limits over
    ISO-TP with extended addressing (0x6F1 -> 0x607), via a reusable
    UdsHandler transport class
    - Contactor control via 0x10B (CRC + alive counter) gated on the 0x53A
    A/B/C/D state indication handshake and a pre-close balancing stop burst
    - Vehicle environment frames (0x12F/0x3A0/0x328/0x3CA/0x3E8/0x2CA) to
    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
2026-06-20 Expand BMW PHEV SME diagnostics (isolation test, DTCs, contactor state)
    Build on the BMW PHEV Gen3/4 SME integration with a fuller diagnostic
    picture from the SME, surfaced on the web UI:
    - Isolation: ext/trg/int resistance and plausibility (UDS 0xDD6A),
    isolation quality (0xD6D9), and an isolation-test routine (0xAD) with
    trigger param (BMS_IsoTest) + 1Hz status/fault polling.
    - DTCs: read (19 02) into a 5-entry code list with count, plus clear,
    driven by BMS_DTCRead / BMS_DTCClear; ECU reset via BMS_Reset.
    - Broadcast decode: 0x1FA contactor/interlock/precharge/weld/emergency/
    service-request state flags, and 0x2F5 charge/discharge voltage limits.
    - Post-contactor voltage (UDS 0xD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
    [param_prj.h, utils.cpp]
2026-06-20 Add Leaf resolver-offset read/write terminal command
    Add a `leafres` VCU terminal command to read and write the Nissan Leaf
    traction-inverter resolver offset over raw CAN (req 0x784 / resp 0x78C,
    KWP2000-style services 0x10/0x21/0x3B). Implemented in LeafINV as a
    synchronous request/response (the 0x78C reply is captured from the CAN
    RX interrupt); terminal glue and the two-step pending-token state live
    in stm32_vcu.cpp.
    Subcommands:
    - read probe records 01/03/04, print the code
    - write <code> preview current vs new + a restore line
    - write <code> confirm apply (exact code must be repeated), then verify
    - probe sweep diagnostic-session sub-f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
    [stm32_vcu.cpp]

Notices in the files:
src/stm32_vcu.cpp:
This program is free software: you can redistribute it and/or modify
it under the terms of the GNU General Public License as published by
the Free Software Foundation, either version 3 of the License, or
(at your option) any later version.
